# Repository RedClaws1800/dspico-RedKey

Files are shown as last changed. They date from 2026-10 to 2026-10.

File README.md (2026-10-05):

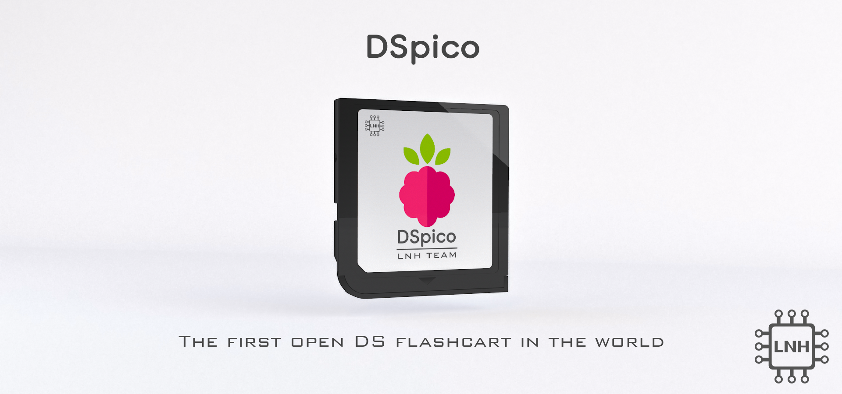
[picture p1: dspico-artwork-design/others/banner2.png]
DSpico-banner


## If you've found this then you probably know what the DSpico is

## THIS IS A FORK FROM THE ORIGINAL PROJECT!!!
(https://github.com/LNH-team/dspico-hardware)

## The main purpose of this project:
 Restore the traditional insertion of a game cartridge into the DS console and having the familiar *pop* of the game appearing on the home screen

# THIS PROJECT IS STILL IN DEVELOPMENT 

what follows is the original repo

# DSpico Hardware
## 🗺️ Contents
- [ℹ Introduction](#ℹ-introduction)
- [❔ About this repository](#-about-this-repository).
- [🎮 DSpico PCB](#-dspico-pcb)
- [🧰 DSpico Shell](#-dspico-shell)
- [🎨 Artwork: Stickers and box art](#-artwork-stickers-and-box-art)
- [📦 Instructions](#-instructions)
- [🛠 Development](#-development)
- [👥 Contributions](#-contributions)
- [👾 Discord](#-discord)
- [📋 LNH Team Statement](#-lnh-team-statement)
- [⚖ License](#-license)

## ℹ Introduction
### What is DSpico?
DSpico is the world's first open-source DS(i) flashcart, created by the LNH team. Everything from the PCB, shell, stickers, and box art is open-source. You can either build it yourself as a DIY project or have it made by a manufacturer.

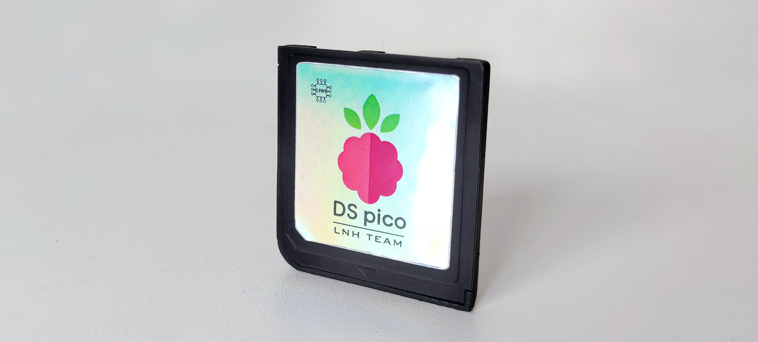
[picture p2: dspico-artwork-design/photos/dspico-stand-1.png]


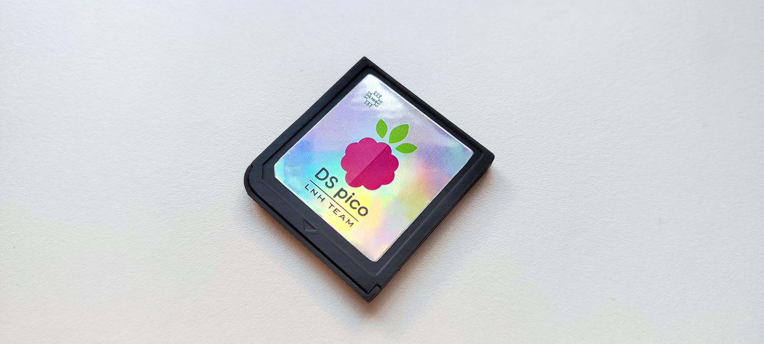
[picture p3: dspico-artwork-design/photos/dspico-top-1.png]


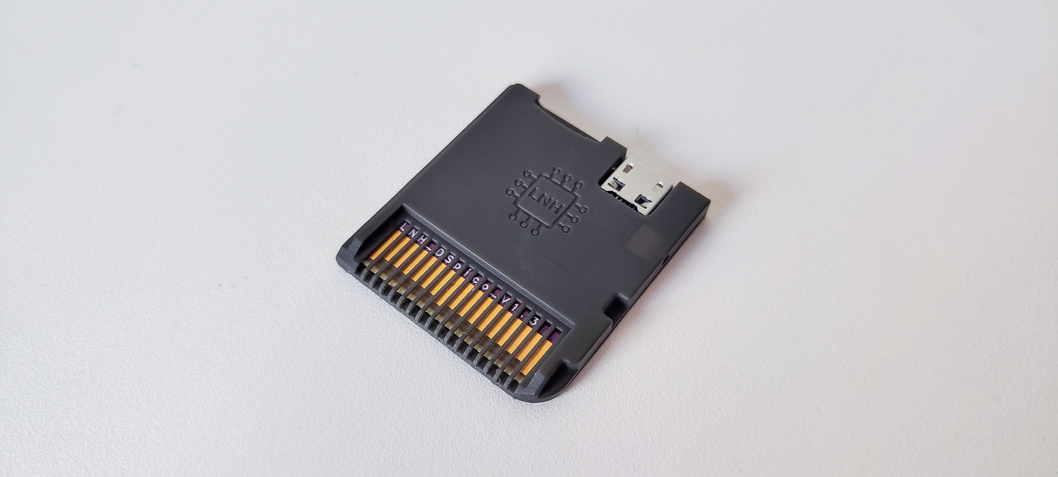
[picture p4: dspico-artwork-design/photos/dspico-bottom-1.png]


### Features
- RP2040 microcontroller
- 16 Mbit flash memory
- Micro USB port
- Micro SD slot
- Development port
- Two LEDs (red and blue)
- Dual power support: can be powered by USB and DS simultaneously (by ORing circuit)

With the [DSpico Firmware](https://github.com/LNH-team/dspico-firmware):
- Sequential SD read speed: up to 6MB/s
- Power consuption: ~57 mW
- Compatible with DSi mode
- Compatible with [Pico Loader](https://github.com/LNH-team/pico-loader) and [Pico Launcher](https://github.com/LNH-team/pico-launcher)

## ❔ About this repository
This repository contains the necessary files for the hardware of the DSpico, including a PCB, CAD design of the shell, stickers for cartridge and box art.

## 🎮 DSpico PCB
The PCB design is located in the [`dspico-pcb`](dspico-pcb) folder. This folder contains all the necessary files for PCB fabrication, as well as the design files created using the electronic design software.

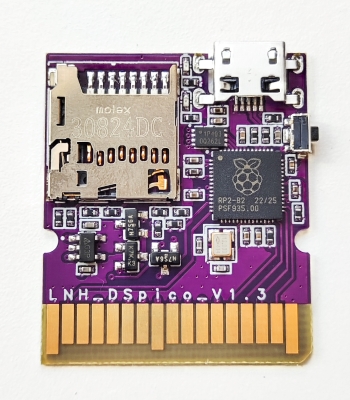
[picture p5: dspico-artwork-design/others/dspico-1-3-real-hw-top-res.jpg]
DSpico-top

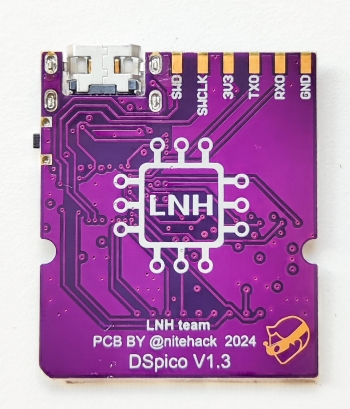
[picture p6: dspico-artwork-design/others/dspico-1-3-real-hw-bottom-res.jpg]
DSpico-bottom

### 📂 Included Subfolders:
- [`design-files`](dspico-pcb/design-files): PCB schematic and layout of DSpico. (KiCad format)
- [`fabrication-files`](dspico-pcb/fabrication-files): Gerber files, Pick&Place files and BOM for PCB fabrication of DSpico.
- [`docs`](dspico-pcb/docs): Documentation for manufacturing and assembling DSpico.

### 🔌 Pinout

| **Peripheral**  | **Pin name - Peripheral** | **Pin name - RP2040** | **Pin number - RP2040** |
|---|---|---|---|
| **DS Slot** | D0 | GPIO12 | 15 |
| | D1 | GPIO13 | 16 |
| | D2 | GPIO14 | 17 |
| | D3 | GPIO15 | 18 |
| | D4 | GPIO16 | 27 |
| | D5 | GPIO17 | 28 |
| | D6 | GPIO18 | 29 |
| | D7 | GPIO19 | 30 |
| | CLK_DS | GPIO11 | 14 |
| | ROM_CS | GPIO10 | 13 |
| | SPI_CS | GPIO21 | 32 |
| | IRQ | GPIO20 | 31 |
| | RST_DS | GPIO09 | 12 |
| **SD slot**| CLK_SD | GPIO03 | 5 |
| | DAT0 | GPIO05 | 7 |
| | DAT1 | GPIO06 | 8 |
| | DAT2 | GPIO07 | 9 |
| | DAT3 | GPIO08 | 11 |
| | CMD | GPIO04 | 6 |
| **DEV port**| SWD | SWD | 25 |
| | SWCLK | SWCLK | 24 |
| | TX | GPIO0 | 2 |
| | RX | GPIO1 | 3 |
| **Blue LED** | LED_B | GPIO28 | 40 |
| **Red LED** | LED_R | GPIO27 | 39 |

## 🧰 DSpico Shell

The CAD design of the shell is located in the [`dspico-shell`](dspico-shell) folder. This folder contains 3D models of the shell (output 3d models and design files), which can be viewed and modified using CAD design software Autodesk Inventor

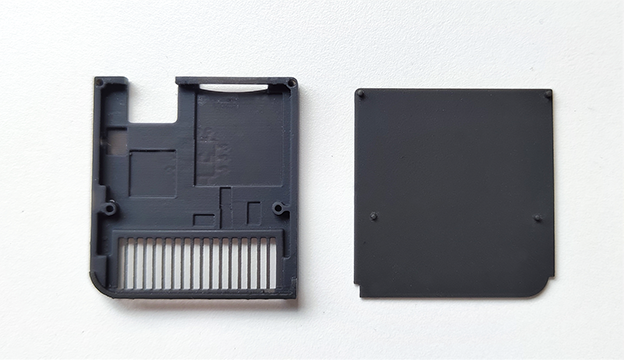
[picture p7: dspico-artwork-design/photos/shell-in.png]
DSpico-shell-in

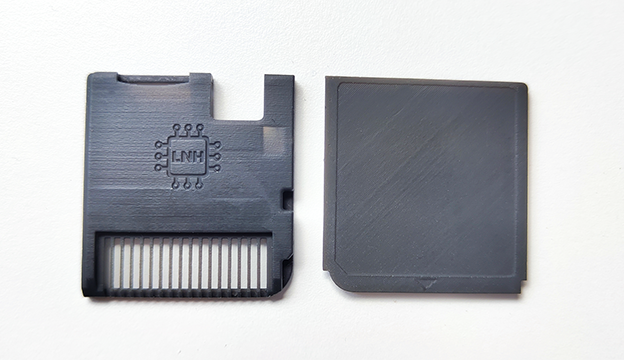
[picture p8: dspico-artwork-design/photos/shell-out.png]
DSpico-shell-out

### 📂 Included Subfolders:
- [`design-files`](dspico-shell/design-files): Contains source design files for the shell
- [`3d-models`](dspico-shell/3d-models): Contains 3D models of the shell in STL and STEP format for fabrication.

## 🎨 Artwork: Stickers and box art
The stickers and box art design are located in the [`dspico-artwork-design`](dspico-artwork-design).  This folder contains stickers for cartridge and box art in SVG, PSD and PNG formats.

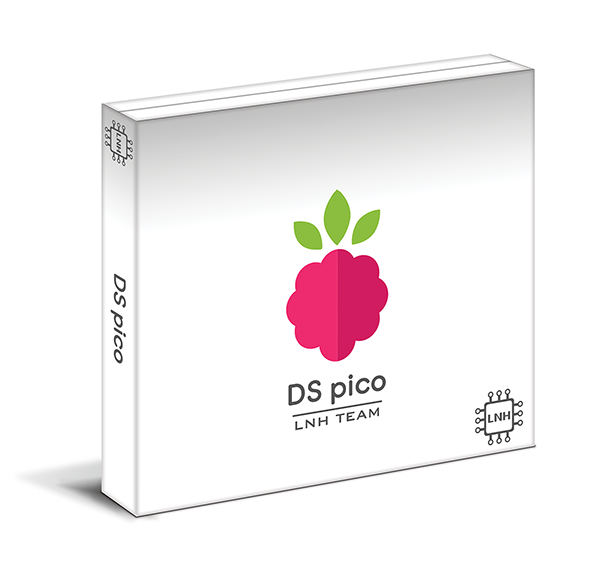
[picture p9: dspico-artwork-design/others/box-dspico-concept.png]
DSpico-box

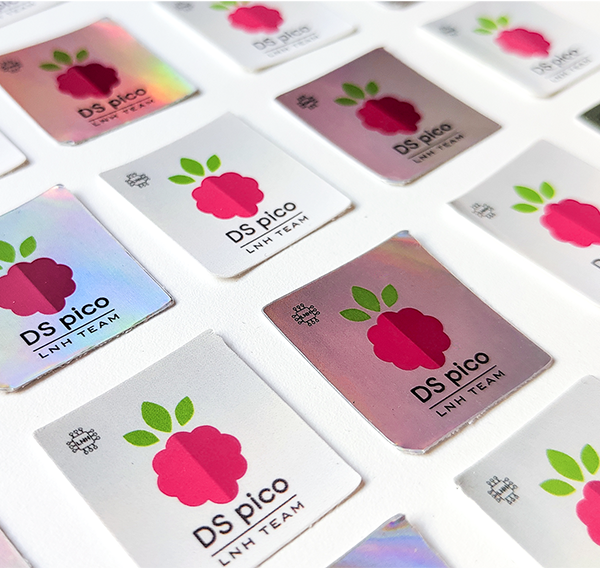
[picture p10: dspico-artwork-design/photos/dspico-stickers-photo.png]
DSpico-stickers


### 📂 Included Subfolders:
- [`stickers`](dspico-artwork-design/stickers): Stickers to print and put on your DSpico cartridge.
- [`box-art`](dspico-artwork-design/box-art): Box art design to print and put on your DS box.
- [`logo`](dspico-artwork-design/logo): DSpico logo in different formats.
- [`others`](dspico-artwork-design/others): Other graphics related to DSpico

## 📦 Instructions
### 1️⃣ Build
1. **Manufacture the PCB and Shell**<br>
    Start by producing both the PCB and the shell. Go to the respective sections, [`dspico-pcb`](dspico-pcb) and [`dspico-shell`](dspico-shell), and read the README file in each to understand how to create these parts.

2. **Optional: Customize with a Sticker and Box Art**<br>
    If desired, you can print a sticker from the stickers section and add box art [`dspico-artwork-design`](dspico-artwork-design) for storing your DSpico (for example, by reusing an existing box).

### 2️⃣ Assembly
Once you have both the PCB and the shell manufactured, the next step is to assemble them. Follow these steps:
1. First, insert the PCB into the bottom part of the shell.
2. Next, attach the top part of the shell by aligning the pegs with the holes in the bottom part.
3. Stick your favorite DSpico sticker on top part.
Make sure everything fits, and your DSpico will be ready for the next steps!

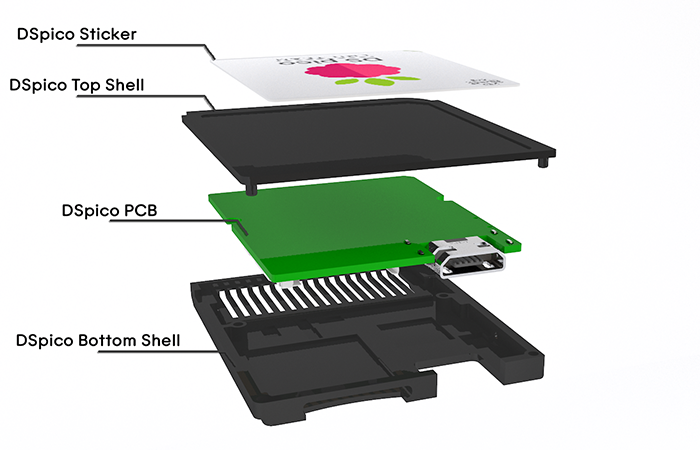
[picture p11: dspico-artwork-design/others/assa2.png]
DSpico-assembly2

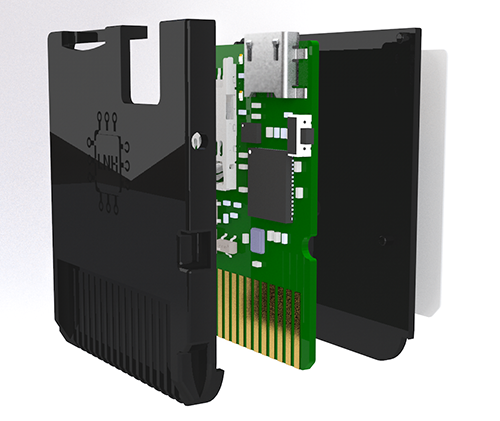
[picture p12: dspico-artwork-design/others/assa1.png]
DSpico-assembly1


### 3️⃣ Setup the software
Follow the [guide](https://github.com/LNH-team/dspico/blob/develop/GUIDE.md) for instructions on how to compile and setup the firmware and the contents of the micro SD card.

## 🛠 Development
The DSpico features a development port for creating new applications and developing new peripherals. The available communication ports are as follows:
- UART
- I2C
- x2 GPIO
- SWD (debug)

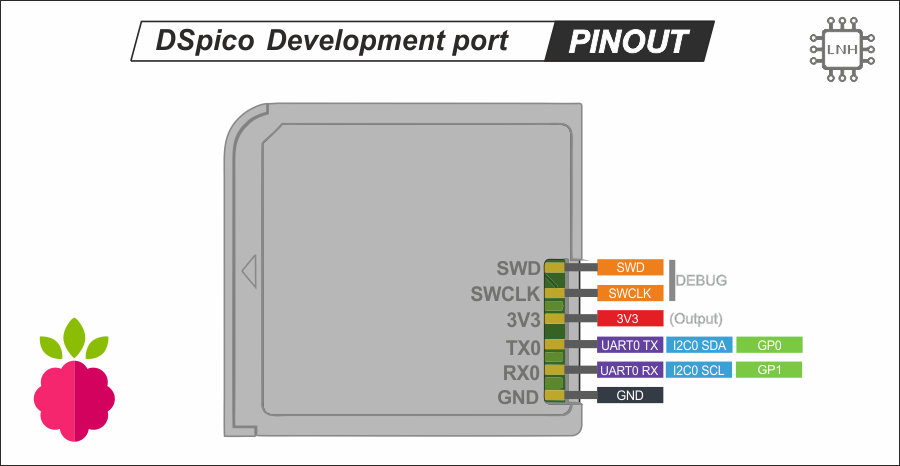
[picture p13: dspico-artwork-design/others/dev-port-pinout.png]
development port


As for the power it can provide to peripherals, it is:
- 3.3 V (up to 50 mA)

The pitch between pins of this port is 2.54 mm such that some connectors can be soldered (as long as it does not interfere with the rest of the DSpico mechanics). For example a male or female header.

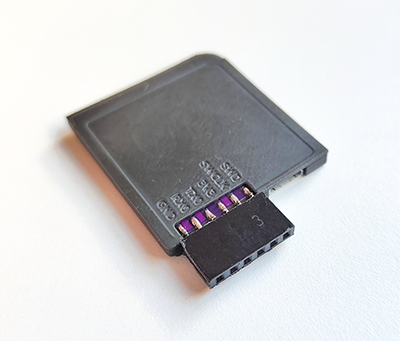
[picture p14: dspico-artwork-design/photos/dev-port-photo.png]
DSpico-dev-port

## 👥 Contributions

Contributions are welcome. If you wish to improve the PCB or shell designs, feel free to submit a pull request!

### Contributors:

#### PCB:
 - [nitehack](https://www.github.com/nitehack)
 - [Gericom](https://github.com/Gericom) (first DSpico prototype)

#### Shell:
 - rcuevas
 - [nitehack](https://www.github.com/nitehack)

#### Artworks:
 - [nitehack](https://www.github.com/nitehack)

## 👾 Discord
- [DS⁽ⁱ⁾ Mode Hacking!](https://discord.gg/fCzqcWteC4)

## 📋 LNH Team Statement
We wish to make it clear that the LNH team has no affiliation with any commercial projects, and we do not endorse or engage in any for-profit endeavors concerning DSpico or related materials. This statement serves as a formal disavowal of any financial or business dealings that may arise in relation to DSpico, and we take no responsibility for any actions or transactions carried out by third parties in this regard.

## ⚖ License

This project is licensed under the CC BY-SA 4.0 License. See the [`LICENSE`](LICENSE) file for more details.

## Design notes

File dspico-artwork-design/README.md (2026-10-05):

# DSpico Artwork Design
Warning: the dimensions of both the stickers and the box could be incorrect so keep this in mind if you intend to print them.

This page is under construction

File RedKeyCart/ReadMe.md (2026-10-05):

### Hoi, Im Red.

and this is a fork

what follows is a readme about the actual end goal

there is another file called "DevLog" that contains detailed info on the whole creation process

this read me is gunna look like shit and im sorry

the whole point of this project is to restore the fun inserting of carts into the DS on a fully modded console.

THIS IS   **N O T**   A WAY TO PIRATE GAMES

the way this system will work is by using the RP2040 and its memory to store a code of which i haven't decided. and this code will be read by custom software loaded onto the DS and will reference a table stored on the SD card and find the corresponding game associated with the ID stored within the cartrage.
That game gets piped into the cartrage slot on the home screen of the DS making the game and its associated cartrage behave like an original unmodded setup.

if you think that is cool and something you'd be interested in then stick around

Please note: This project is in a extremely early state with virtually nothing to show for it

Looking for C/C++ programmers, will pay

Looking for ARM assembly programmers to hug and pay

if you like my dumb writing style please feel free to read the Dev Log

<3

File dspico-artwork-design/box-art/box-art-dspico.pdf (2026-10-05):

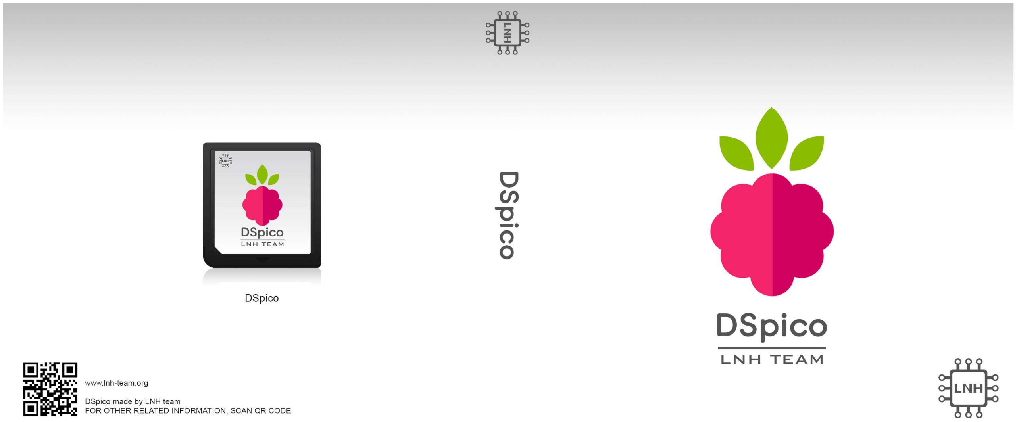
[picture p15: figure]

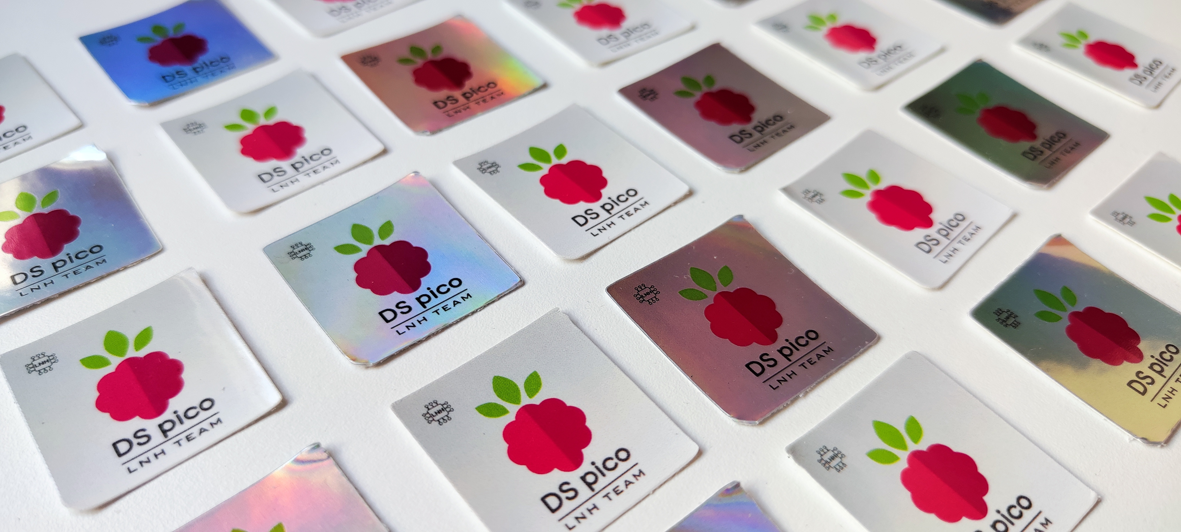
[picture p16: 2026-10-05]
dspico-artwork-design/photos/stickers.jpg

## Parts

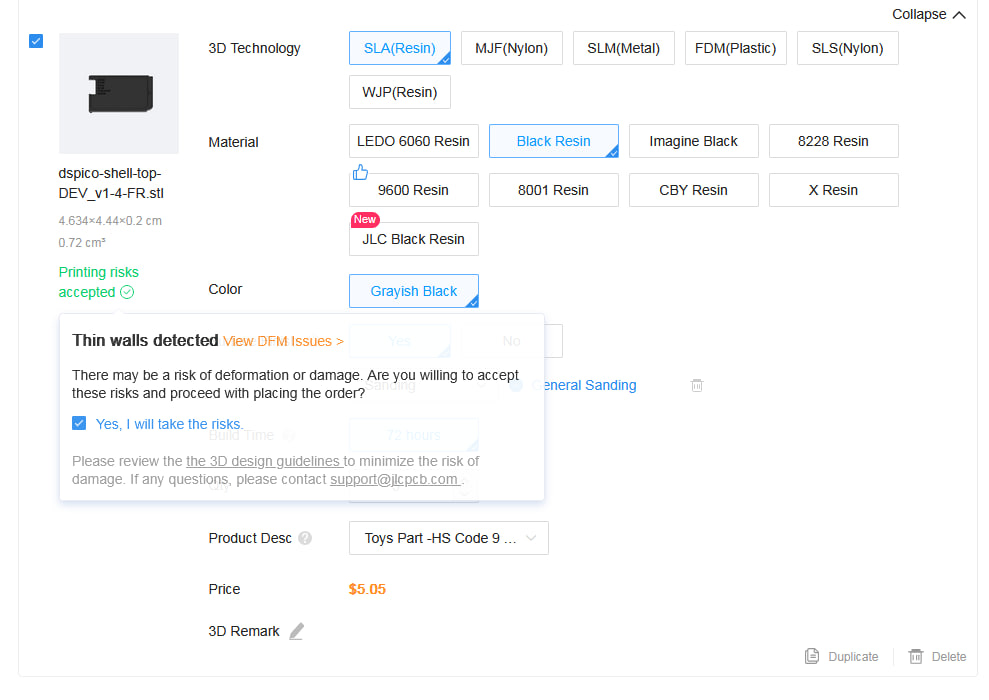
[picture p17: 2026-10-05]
dspico-artwork-design/guides/3d-order-warn.jpg

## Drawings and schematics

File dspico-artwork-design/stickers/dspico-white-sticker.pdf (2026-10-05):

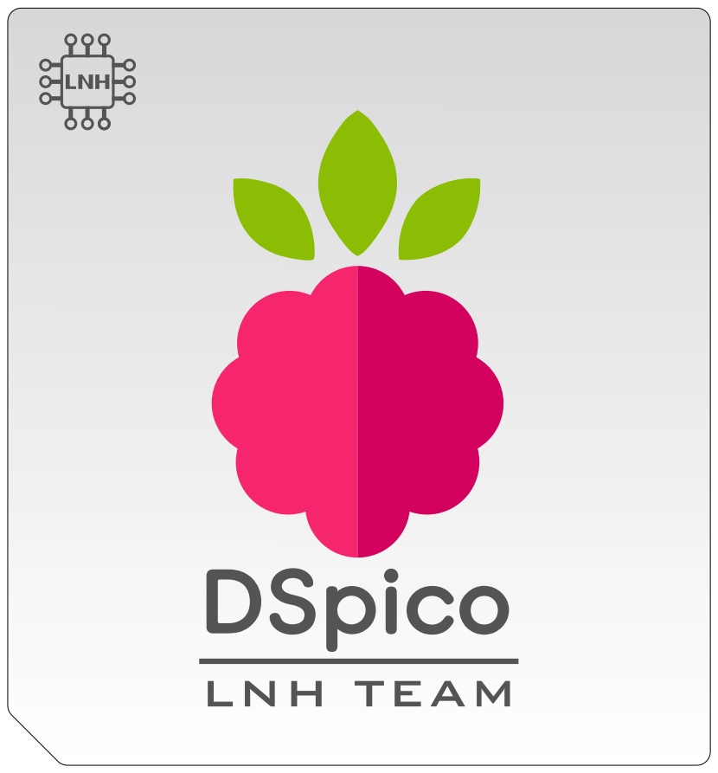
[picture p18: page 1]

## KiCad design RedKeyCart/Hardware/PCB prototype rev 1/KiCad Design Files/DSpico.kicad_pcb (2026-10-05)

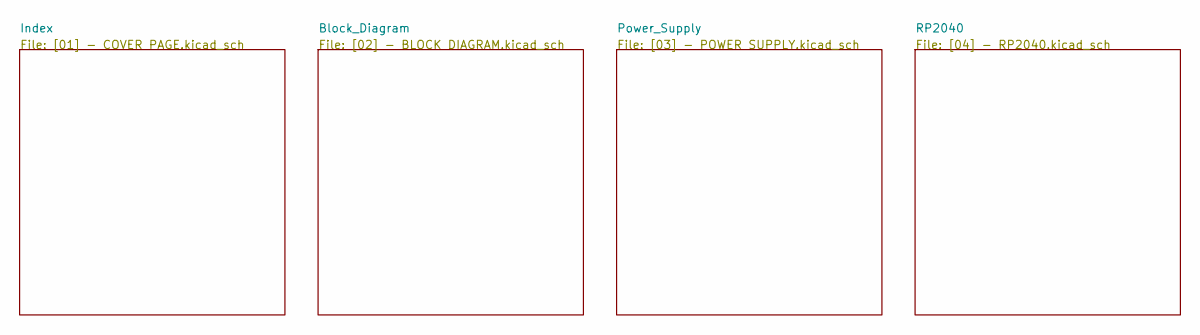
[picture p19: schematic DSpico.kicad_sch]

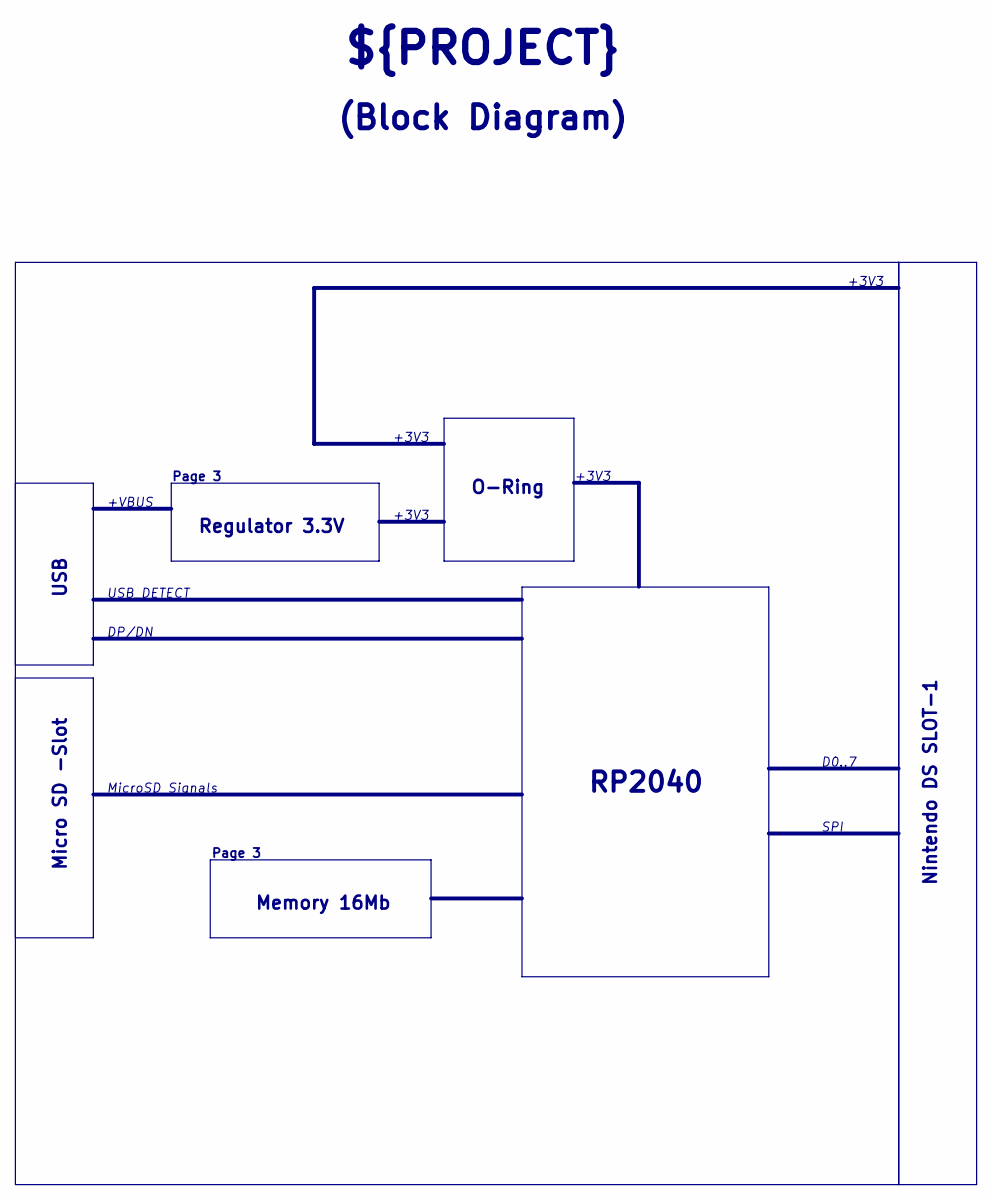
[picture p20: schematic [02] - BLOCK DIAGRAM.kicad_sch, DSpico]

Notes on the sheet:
+VBUS
+3V3
RP2040
Page 3
(Block Diagram)
USB_DETECT
D0..7
SPI
O-Ring
USB
MicroSD Signals
Regulator 3.3V
Nintendo DS SLOT-1
DP/DN
${PROJECT}
Micro SD -Slot
Memory 16Mb

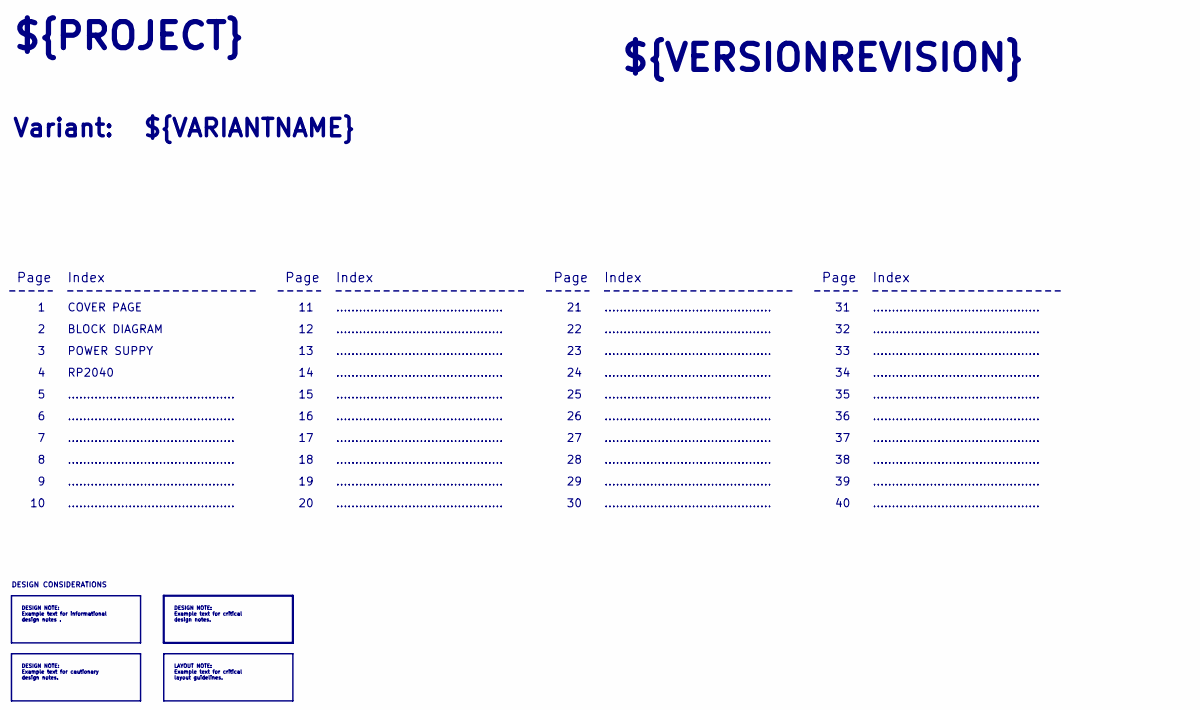
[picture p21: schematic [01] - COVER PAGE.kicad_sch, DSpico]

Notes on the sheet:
Page
............................................
POWER SUPPY
COVER PAGE
${VARIANTNAME}
Index
BLOCK DIAGRAM
${PROJECT}
DESIGN CONSIDERATIONS
RP2040
${VERSIONREVISION}
Variant:
DESIGN NOTE: Example text for cautionary design notes.
DESIGN NOTE: Example text for informational design notes .
DESIGN NOTE: Example text for critical design notes.
LAYOUT NOTE: Example text for critical layout guidelines.

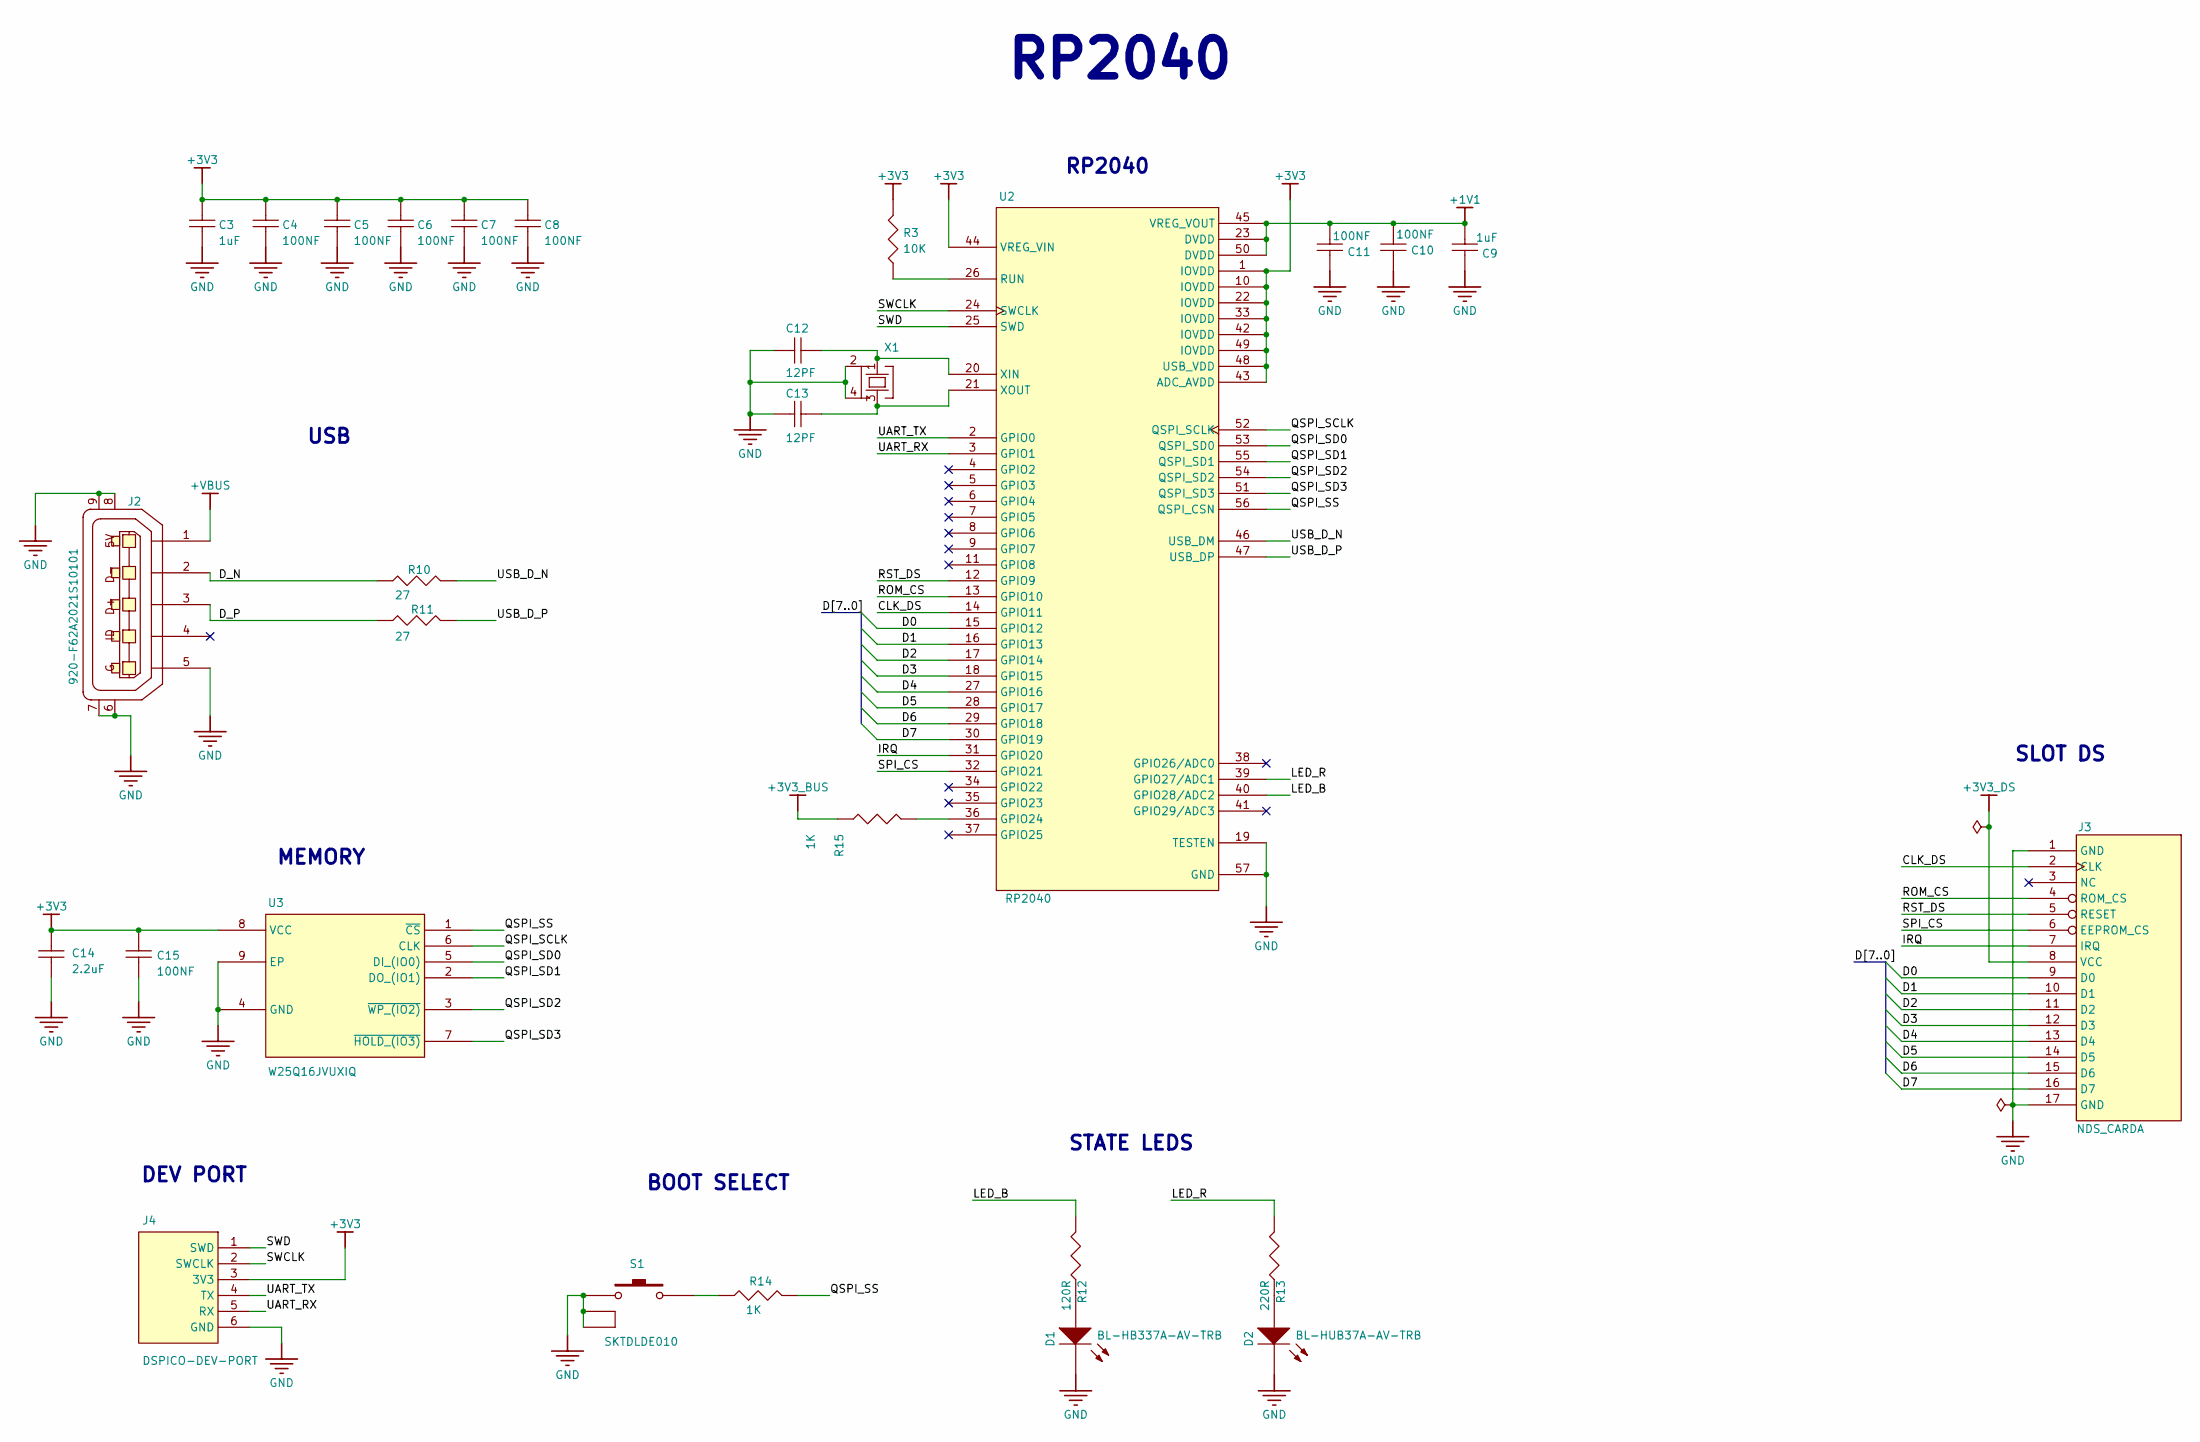
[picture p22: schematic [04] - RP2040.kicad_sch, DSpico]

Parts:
C3, C9: 1uF; C0402; TOLERANCE 10%; VOLTAGE RATING 25V; MANUFACTURER PART NUMBER C1005X5R1E105K050BC
C4, C5, C6, C7, C8, C10, C11, C15: 100NF; C0402; TOLERANCE 10%; VOLTAGE RATING 16V; MANUFACTURER PART NUMBER GRM155R71C104KA88D
C12, C13: 12PF; C0402; TOLERANCE 5%; VOLTAGE RATING 50V; MANUFACTURER PART NUMBER 04025A120JAT2A
C14: 2.2uF; C0402; MANUFACTURER PART NUMBER C1005X5R1A225K050BC
D1: BL-HB337A-AV-TRB; LED0402-RD; FORWARD VOLTAGE 2.8V; MANUFACTURER PART NUMBER BL-HB337A-AV-TRB
D2: BL-HUB37A-AV-TRB; LED0402-RD; FORWARD VOLTAGE 2V; MANUFACTURER PART NUMBER BL-HUB37A-AV-TRB
J2: 920-F62A2021S10101; MICRO-USB_MICRO-USB-31
J3: NDS_CARDA; NDS_CARD
J4: DSPICO-DEV-PORT; EP_DEV_PORT; CURRENT RATING ?; VOLTAGE RATING 3.3V; MANUFACTURER PART NUMBER PICO-DEVELOP-PORT
R3: 10K; R0402; TOLERANCE 1%; POWER RATING 63mW; MANUFACTURER PART NUMBER CRCW040210K0FKED
R10, R11: RC0402FR-0727RL; R0402; WORKING VOLTAGE 50V; TOLERANCE 1%
R12: 120R; R0402; VOLTAGE RATING 50V; POWER RATING 62.5mW; MANUFACTURER PART NUMBER RC0402FR-07120RL
R13: 220R; R0402; VOLTAGE RATING 50V; POWER RATING 62.5mW; MANUFACTURER PART NUMBER RC0402FR-07220RL
R14, R15: 1K; R0402; TOLERANCIA DE RESISTENC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 ± 1%; MANUFACTURER PART NUMBER CRCW04021K00FKED
S1: SKTDLDE010; KEY-SMD_SKTDLDE010; MANUFACTURER PART NUMBER SKTDLDE010
U2: RP2040; QFN40P700X700X90-57N
U3: W25Q16JVUXIQ; SON50P300X200X60-9N
X1: XYDBPCNANF-12MHZ; OSC-SMD_4P-L2.5-W2.0-BL

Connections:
+1V1: C9.2, C10.2, C11.2, U2.23 (DVDD), U2.45 (VREG_VOUT), U2.50 (DVDD)
+3V3: C3.2, C4.2, C5.2, C6.2, C7.2, C8.2, C14.2, C15.2, J4.3 (3V3), R3.2, U2.1 (IOVDD), U2.10 (IOVDD), U2.22 (IOVDD), U2.33 (IOVDD), U2.42 (IOVDD), U2.43 (ADC_AVDD), U2.44 (VREG_VIN), U2.48 (USB_VDD), U2.49 (IOVDD), U3.8 (VCC); also elsewhere on the board
+3V3_BUS: R15.1; also elsewhere on the board
+3V3_DS: J3.8 (VCC); also elsewhere on the board
+VBUS: J2.1; also elsewhere on the board
/RP2040/CLK_DS: J3.2 (CLK), U2.14 (GPIO11)
/RP2040/D0: J3.9 (D0), U2.15 (GPIO12)
/RP2040/D1: J3.10 (D1), U2.16 (GPIO13)
/RP2040/D2: J3.11 (D2), U2.17 (GPIO14)
/RP2040/D3: J3.12 (D3), U2.18 (GPIO15)
/RP2040/D4: J3.13 (D4), U2.27 (GPIO16)
/RP2040/D5: J3.14 (D5), U2.28 (GPIO17)
/RP2040/D6: J3.15 (D6), U2.29 (GPIO18)
/RP2040/D7: J3.16 (D7), U2.30 (GPIO19)
/RP2040/D_N: J2.2, R10.1
/RP2040/D_P: J2.3, R11.1
/RP2040/IRQ: J3.7 (IRQ), U2.31 (GPIO20)
/RP2040/LED_B: R12.2, U2.40 (GPIO28/ADC2)
/RP2040/LED_R: R13.2, U2.39 (GPIO27/ADC1)
/RP2040/QSPI_SCLK: U2.52 (QSPI_SCLK), U3.6 (CLK)
/RP2040/QSPI_SD0: U2.53 (QSPI_SD0), U3.5 (DI_(IO0))
/RP2040/QSPI_SD1: U2.55 (QSPI_SD1), U3.2 (DO_(IO1))
/RP2040/QSPI_SD2: U2.54 (QSPI_SD2), U3.3 (~WP_(IO2))
/RP2040/QSPI_SD3: U2.51 (QSPI_SD3), U3.7 (~HOLD_(IO3))
/RP2040/QSPI_SS: R14.2, U2.56 (QSPI_CSN), U3.1 (~CS)
/RP2040/ROM_CS: J3.4 (ROM_CS), U2.13 (GPIO10)
/RP2040/RST_DS: J3.5 (RESET), U2.12 (GPIO9)
/RP2040/SPI_CS: J3.6 (EEPROM_CS), U2.32 (GPIO21)
/RP2040/SWCLK: J4.2 (SWCLK), U2.24 (SWCLK)
/RP2040/SWD: J4.1 (SWD), U2.25 (SWD)
/RP2040/UART_RX: J4.5 (RX), U2.3 (GPIO1)
/RP2040/UART_TX: J4.4 (TX), U2.2 (GPIO0)
/RP2040/USB_D_N: R10.2, U2.46 (USB_DM)
/RP2040/USB_D_P: R11.2, U2.47 (USB_DP)
GND: C3.1, C4.1, C5.1, C6.1, C7.1, C8.1, C9.1, C10.1, C11.1, C12.1, C13.1, C14.1, C15.1, D1.1, D2.1, J2.5, J2.6, J2.7, J2.8, J2.9, J3.1 (GND), J3.17 (GND), J4.6 (GND), S1.1, S1.3, S1.4, U2.19 (TESTEN), U2.57 (GND), U3.4 (GND), U3.9 (EP), X1.2, X1.4; also elsewhere on the board
unnamed: D1.2, R12.1
unnamed: D2.2, R13.1
unnamed: R14.1, S1.2
unnamed: R15.2, U2.36 (GPIO24)
unnamed: R3.1, U2.26 (RUN)
unnamed: C12.2, U2.20 (XIN), X1.1
unnamed: C13.2, U2.21 (XOUT), X1.3

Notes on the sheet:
MEMORY
BOOT SELECT
RP2040
SLOT DS
STATE LEDS
DEV PORT
USB

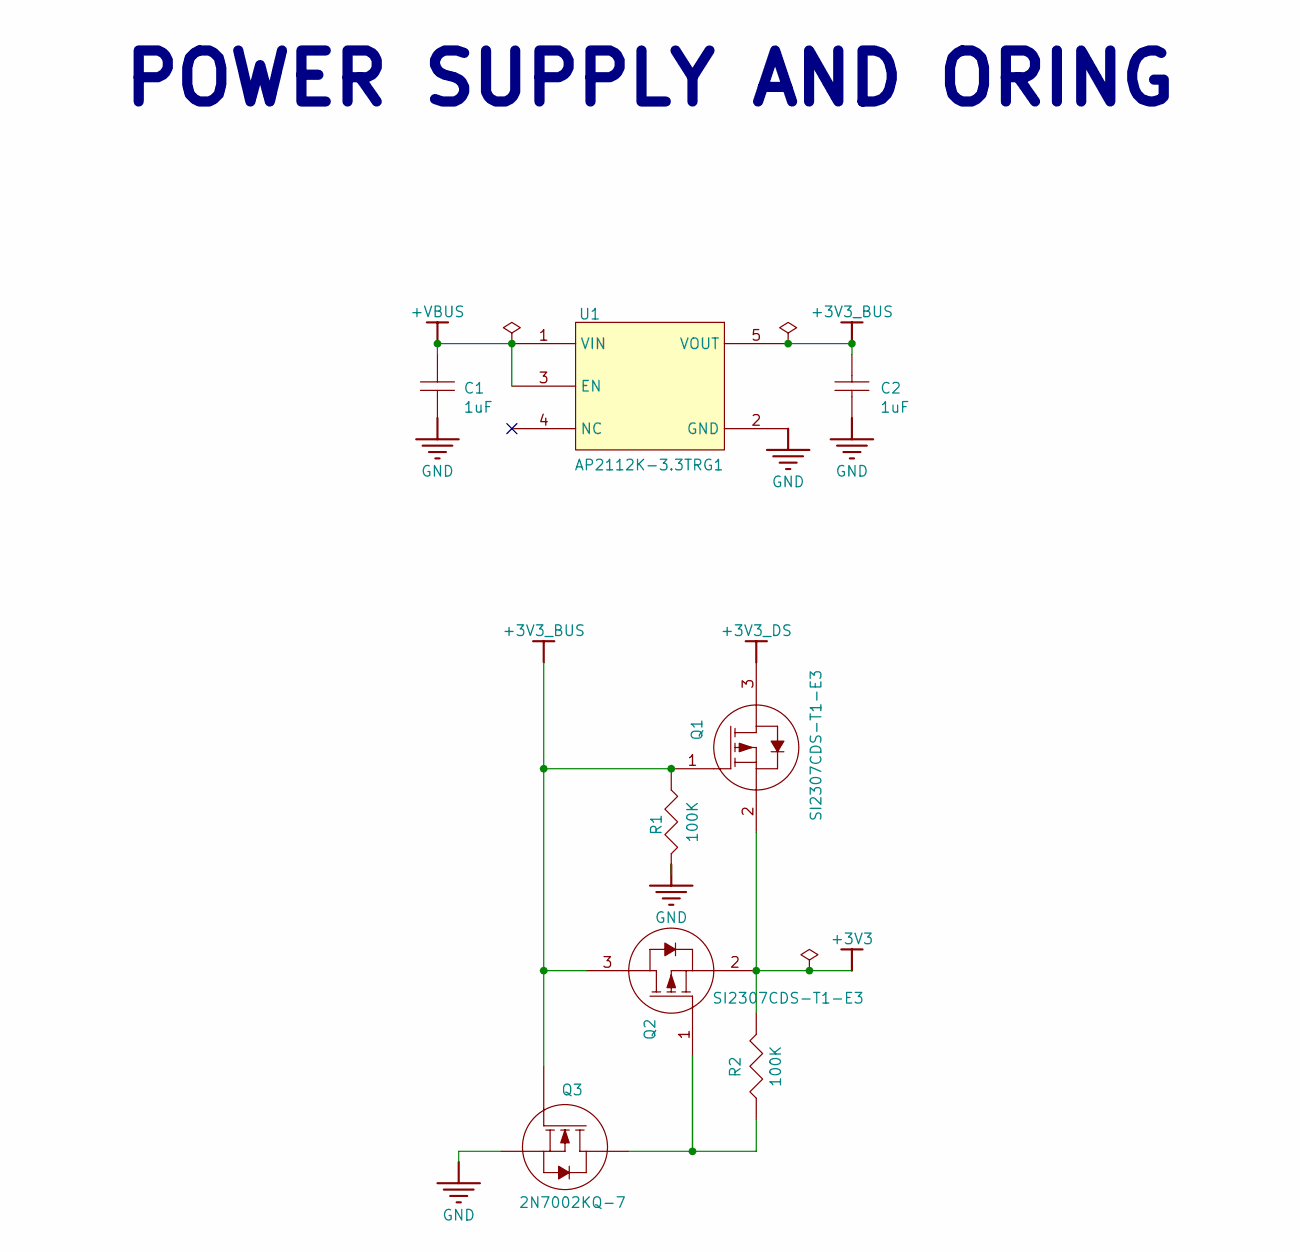
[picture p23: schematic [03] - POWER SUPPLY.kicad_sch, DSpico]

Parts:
C1, C2: 1uF; C0402; TOLERANCE 10%; VOLTAGE RATING 25V; MANUFACTURER PART NUMBER C1005X5R1E105K050BC
Q1, Q2: SI2307CDS-T1-E3; SOT-23_L2.9-W1.3-P1.90-LS2.4-BR
Q3: 2N7002KQ-7; SOT-23_L2.9-W1.3-P1.90-LS2.4-BR; MANUFACTURER PART NUMBER 2N7002KQ-7
R1, R2: 100K; R0402; TOLERANCE 1%; POWER RATING 63mW; MANUFACTURER PART NUMBER CRCW0402100KFKED
U1: AP2112K-3.3TRG1; SOT95P285X140-5N; DROPOUT VOLTAGE 250mV; OUTPUT VOLTAGE 3.3V; MANUFACTURER PART NUMBER AP2112K-3.3TRG1

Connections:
+3V3: Q1.2 (S), Q2.2 (S), R2.2; also elsewhere on the board
+3V3_BUS: C2.2, Q1.1 (G), Q2.3 (D), Q3.1 (G), R1.1, U1.5 (VOUT); also elsewhere on the board
+3V3_DS: Q1.3 (D); also elsewhere on the board
+VBUS: C1.2, U1.1 (VIN), U1.3 (EN); also elsewhere on the board
GND: C1.1, C2.1, Q3.2 (S), R1.2, U1.2 (GND); also elsewhere on the board
unnamed: Q2.1 (G), Q3.3 (D), R2.1

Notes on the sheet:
POWER SUPPLY AND ORING

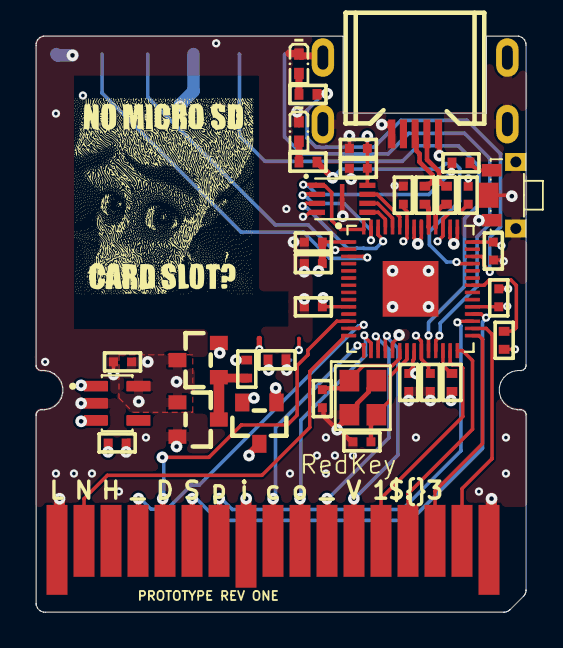
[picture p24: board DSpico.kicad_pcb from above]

Board: 4 copper layers, 27.2 x 32.0 mm, 37 parts (1 on the bottom side), 43 nets.

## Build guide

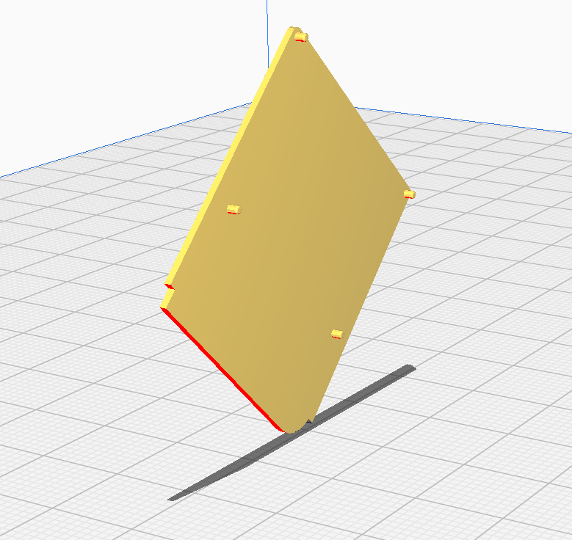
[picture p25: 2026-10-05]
dspico-artwork-design/guides/top-shell-orientation.png

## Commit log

2026-10-05 Create RedKeyCart-PCB
2026-10-05 Update hiReadMe with PCB prototype changes
    Added details about the PCB prototype changes, including the removal of the Micro SD Card Slot and updates to the schematic.
2026-10-05 Added Design Files
    [DSpico.kicad_pcb, DSpico.kicad_sch, [01] - COVER PAGE.kicad_sch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]
